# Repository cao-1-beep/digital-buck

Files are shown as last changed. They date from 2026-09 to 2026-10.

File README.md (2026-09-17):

# digital-buck

> 个人硬件项目：数字buck电源

## 项目内容

- `digital_buck/buck-firmware/Core/Inc/adc.h`
- `digital_buck/buck-firmware/Core/Inc/key.h`
- `digital_buck/buck-firmware/Core/Inc/main.h`
- `digital_buck/buck-firmware/Core/Inc/pid.h`
- `digital_buck/buck-firmware/Core/Inc/protect.h`
- `digital_buck/buck-firmware/Core/Inc/pwm.h`
- `digital_buck/buck-firmware/Core/Inc/stm32f1xx_hal_conf.h`
- `digital_buck/buck-firmware/Core/Inc/stm32f1xx_it.h`
- `digital_buck/buck-firmware/Core/Inc/storage.h`
- `digital_buck/buck-firmware/Core/Inc/uart.h`
- `digital_buck/buck-firmware/Core/Src/adc.c`
- `digital_buck/buck-firmware/Core/Src/key.c`
- `digital_buck/buck-firmware/Core/Src/main.c`
- `digital_buck/buck-firmware/Core/Src/pid.c`
- `digital_buck/buck-firmware/Core/Src/protect.c`
- `digital_buck/buck-firmware/Core/Src/pwm.c`
- `digital_buck/buck-firmware/Core/Src/stm32f1xx_it.c`
- `digital_buck/buck-firmware/Core/Src/storage.c`
- `digital_buck/buck-firmware/Core/Src/uart.c`
- `digital_buck/buck-firmware/readme.md`
- `digital_buck/keil_digital_buck.uvprojx`
- `drill.pdf`
- `keil_digital_buck.uvprojx`
- `PCB_Project/buck.PcbDoc`
- `PCB_Project/buck.SchDoc`
- `PCB_Project/digital_buck.OutJob`
- `PCB_Project/digital_buck.pdf`
- `PCB_Project/digital_buck.PrjPcb`
- `PCB_Project/digital_buck.PrjPcbStructure`
- `PCB_Project/digital_buck.xlsx`

## 使用工具

- **Altium Designer** —— 原理图 / PCB
- **Keil MDK + STM32** —— 固件源码

## 说明

- 本项目为个人学习与实践记录，供参考交流。
- 打样/复现前请自行复核原理图、器件参数与制板输出。
- 仓库内不含编译产物、仿真原始数据与第三方资料压缩包。

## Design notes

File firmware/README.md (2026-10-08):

# 数字降压电源 · 固件(DBC-2)

> 目标板:`hardware\digital-buck\PCB_Project\buck.SchDoc` / `buck.PcbDoc`(**板子已打样,硬件按原理图为准**)
> 主控:STM32F103C8T6 · 半桥同步整流(RT9624AZS + XR20N04 ×2)· L1 = 68μH
> 规格(2026-10-08 定):**输入 15 ~ 25V,输出 5 ~ 10V,≤ 2A**

---

## 一、你要做的 4 步

1. Keil 打开 **`MDK-ARM\DigitalBuck.uvprojx`**
2. `Build`(F7)
3. **第一次先选调试器**:`Options for Target`(Alt+F7)→ **Debug** 页 → 右上 `Use:` 选 **ST-Link Debugger**
   (工程从你的 `MOTOR.uvprojx` 派生,但我**没有给 `.uvoptx`** —— 调试器的选择存在那里,我不猜你 Keil 里 ST-Link 那条的驱动名。选一次以后 Keil 自己记住。)
4. `Download`(F8)

> **台架务必用限流电源。** 板上和电源端都没有保险丝,而**这颗板没有硬件过流比较器**(两颗运放 U2/U3 都用掉了),过流全靠软件,响应约几十μs。

---

## 二、你改过的 5 个元件(固件系数就是按它们推的)

| 元件 | 原值 | **现值** | 为什么改 | 对固件的影响 |
|:--|:--|:--|:--|:--|
| **R11** | 10mR | **30mR** | 提高信噪比;同时把运放失调折算的电流误差从 ±700mA 降到 ±233mA | 电流灵敏度 |
| **R19** | 100K | **30K** | 增益 50 → 15.7,采样链带宽 **20kHz → 64kHz** | **0.4706 V/A** |
| **C11** | 100nF | **1nF** | 采样极点 1.6kHz → 106kHz,不再是瓶颈 | 环路带宽 |
| **R20** | 10K | **3.3K** | 输出电压量程 6.6V → **13.3V** | Vout 分压 **0.2481** |
| **R30** | 1K | **68Ω** | NTC 饱和点从 ≈58°C 抬到 ≈150°C | NTC 换算 |

**? 如果以后有人把这些改回去,`adc.h` 里的系数必须同步改,否则读数全错。**

---

## 三、引脚表(原理图 + PCB 网表双证)

| MCU | 网络 | 用途 |
|:--|:--|:--|
| **PA10** | `PWM` | **单路 PWM → U4.RT9624 脚2**(TIM1_CH3) |
| **PA6** | `CUR_ADC` | 输出电流(U2 = LMV321 放大 15.7 倍,偏置 0.3765V) |
| **PA5** | `VIN_ADC` | 输入电压(U5B 缓冲,R21=10k/R23=1k ? 1:11) |
| **PA7** | `VFB_ADC` | 输出电压(U3 缓冲,R6=10K/R20=3.3K ? 0.2481) |
| **PA4** | `TEP_ADC` | 外部 NTC(MF52A103F3950,经 U5A 缓冲) |
| **PA1/PA2/PA3/PA0** | `PA1/PA2/PA3/PA0` | S1 电压+ / S2 电压? / S3 开关机 / S5 保存 |
| **PB6 / PB7** | `SCL` / `SDA` | I2C OLED(P4 排针) |
| **PA13 / PA14** | `SWDIO` / `SWCLK` | P3 排针 = 下载口 |
| NRST | `NRST` | 复位电路 + **S4 复位键** |

**板上没有**:LED(PC13 未连)、串口(PA9 悬空、PA10 已被 PWM 占用)、PB3/PB4/PB13~PB15。
电源链:`VIN` → U8(MG78M12N3)→ `+12` → U6(SPX1117-5.0)→ `+5` → U7(SPX1117-3.3)→ `+3.3V`

> **?? 单路 PWM,不是互补。** RT9624AZS 是单 PWM 输入、内部自产 UGATE/LGATE 和死区的半桥驱动 ?
> **死区由硬件给,固件不设 DTG**。原代码里的 `TIM1_CH1(PA8) + CH1N(PB13) 互补 + 100ns 死区`
> 在原理图和 PCB 上都没有对应引脚。

---

## 四、模拟前端系数(全部从原理图的电阻网推出来)

| 量 | 公式 | 量程 |
|:--|:--|:--|
| **输出电流** | `I[A] = (V_adc ? 0.3765) / 0.4706` | **?0.80 ~ +6.21A**(零电流 ≈ ADC 467) |
| **输入电压** | `Vin = V_adc × 11` | 36.3V |
| **输出电压** | `Vout = V_adc / 0.2481` | 13.3V |
| **温度** | `ratio = V_ntc / Vin`,`R_NTC = 68 × (1/ratio ? 1)`,`T[K] = 1/(1/298.15 + ln(R_NTC/10000)/3950)` | 0 ~ 150°C(≈22 码/°C) |

**三点说明:**
- **电流偏置 0.3765V 是算出来的,不是猜的**:1.2V 基准经 `R3(100K)/R5(1k)` 往 IN+ 注 23.5mV,再被增益放大 → 增益 51 时正好是 1.2V,你把增益改成 16 之后就变成 **0.3765V**。这也让**负向量程从 ?2.4A 缩到 ?0.80A**(你采的是单向负载电流,够用)。
- **上电会做电流零点标定**(输出关断时采 8 轮取平均),所以 LMV321 的输入失调(±7mV ? ±233mA)被吃掉。
- **NTC 是比例式**(以 VIN 为参考),`Vin` 自动消掉 —— 但 0°C 以下分辨率很差,所以**只用它做过温,不做低温判断**。

---

## 五、控制架构(这是相对原代码改动最大的地方)

```
电压外环 PID(5kHz) ──Icmd──> 电流内环 PID(50kHz) ──Duty──> TIM1_CH3(PA10) ──> RT9624 ──> 半桥
        ↑ Vout(PA7)                    ↑ Iout(PA6)                                     ↓
        └──────────── ADC1 四通道,TIM1 TRGO 触发 + DMA 环形 ?──────────────────────── L1/Vout
```

| 层 | 频率 | 干什么 | 为什么 |
|:--|:--|:--|:--|
| PWM 更新中断 | **100kHz** | 读电流(2 次浮点运算)+ **逐周期限流整数比较** + 分频计数 | 限流要快 |
| 电流内环 | **50kHz** | PID → 占空比 | 采样链带宽 64kHz(运放 GBW/增益),50kHz 采样终于是有意义的 |
| 电压外环 | **5kHz** | PID → 电流指令 | 电压环本来就慢 |
| 主循环 | — | Vin/Vout/NTC 换算、按键、OLED、Flash | 慢变量,不在中断里做 |

**为什么必须分频**:原代码在 10μs(720 周期)的预算里做 ADC 的浮点平均(12 次 int→float + 12 次加)+ 保护 + PID,按实际调用链估算 **15~29μs,超预算 1.5~3 倍**。分频后中断里最坏约 **12~15 次浮点运算 ≈ 300~400 周期**,余量约 2 倍。

> **上板后请用一个空闲 GPIO 在中断进出处翻转,示波器量实际宽度。** 估算不等于实测。

---

## 六、保护(全部软件)

| 层 | 阈值 | 动作 | 响应 |
|:--|:--|:--|:--|
| ① 逐周期限流 | **2.0A**(可改,0.1~2.0) | 本周期占空比压 0,下周期自动恢复 | **10μs** |
| ② 硬跳闸 | **3.2A**,连续 3 个周期 | 锁存 + 关输出,OLED 报 `OCP` | 30μs |
| ③ 输入欠压 | < 13.0V(消抖 50ms) | 关输出;回到 13.5V 自动清位(输出不自动开) | ms |
| ④ 输入过压 | > 26.5V(消抖 20ms) | 同上 | ms |
| ⑤ 输出过压 | > VSET×1.10 或 > 11.0V(3ms) | 锁存 | ms |
| ⑥ 过温 | **> 85°C**(100ms) | 锁存;回落到 75°C 以下才允许清除 | 100ms |
| ⑦ 过温降额 | **70°C 起** | 限流点从 2.0A 线性收到 1.0A | 100ms |

**?? 为什么跳闸是 3.2A 而不是更高**:电感 `L1 = xr1050-680m` 的**饱和电流只有 3.8A**,而最坏工况(25V→10V/2A)的纹波是 0.88A p-p ? 半纹波 0.44A。`3.2 + 0.44 = 3.64A < 3.8A`,**故障时电感也不会饱和**。跳闸点若设到 3.6A,峰值会到 4.04A,**超过饱和点** —— 电感一旦饱和,后面电流就失控了。

**本板没有硬件过流比较器**,所以过流全靠上面 ① ② 两层。台架必须用限流电源。

---

## 七、界面与按键

**OLED(PB6=SCL / PB7=SDA,I2C)** 4 行状态页:

```
SET 5.00V   CV|CC|故障名      第1行:设定值 + 模式(有故障时显示 OCP/OTP/OVIN/UVIN)
OUT 5.02V                     第2行:实际输出电压
IO  1.25A   LMT               第3行:输出电流(限流触发时亮 LMT,保持 1 秒)
IN 15.2V    42C               第4行:输入电压 + 温度
```

**按键**(按下为低;板上已有 10K 上拉 + 100nF,固件再开内部上拉做双保险):

| 键 | 引脚 | 短按 | 长按(800ms) | 长按后连按 |
|:--|:--|:--|:--|:--|
| S1 | PA1 | 电压 +0.1V | +0.5V | +0.1V/150ms |
| S2 | PA2 | 电压 ?0.1V | ?0.5V | ?0.1V/150ms |
| S3 | PA3 | 开关机 | **清故障** | — |
| S5 | PA0 | **保存参数**(停机时才允许) | **恢复出厂默认** | — |

**S4 是复位键(接 NRST)**,固件里不存在。

**上电默认关闭输出**,必须按 S3 才输出。

---

## 八、台架调试顺序

> 前 3 步不要接负载。

1. **只上 3.3V**(可从 P3.1 供)。看 OLED 是否亮、显示 `SET 5.00V CV`。不亮 → 先查 PB6/PB7 与上拉。
2. **量 PA10 静止电平**:应为**低**(MOE=0 + OSSI=1 ? 主动拉低)。若悬空/高 ? 查 `PWM_Init` 的 OSSI 配置。
3. **按 S3 开机**,示波器看 PA10:应有 **100kHz 方波**,占空比随软启动从 0 升到约 42%。频率不对 → 查 Y1(应为 8MHz)。
4. **电流零点**:开机后 OLED 的 `IO` 应显示 ≈ 0.00A(上电已自动标定)。若明显非零 → 用 `ADC_GetZeroRaw()` 在 Keil Watch 里看,正常约 467。
5. **接限流电源(先限到 0.2A)、不接负载**,确认 Vin 读数与电源表一致(分压 1:11)。
6. **接电子负载**,从 0.2A 慢慢加,看 `IO` 读数与外部分流器是否一致。不一致就按实测改 `ADC_IOUT_V_PER_A`。
7. **PID 整定**:
   - **先内环**:`Control_SetIpid(0.05, 200, 0)` 起步,加负载看阶跃;振荡→减 Kp/Ki,太慢→加。
   - **再外环**:`Control_SetVpid(0.3, 50, 0)` 起步,同理。
   - 用 **Keil 的 Watch 窗口 + Logic Analyzer**(通过 SWD 周期性读变量)把 `duty`/`ADC_GetIout()`/`ADC_GetVout()` 画成曲线 —— **不需要额外硬件**。
8. **过温**:用热风枪或电烙铁靠近 NTC,看 OLED 温度上升、70°C 起 `IO` 上限被压低、85°C 报 `OTP` 停机。
9. **过流**:把负载设成恒流 2.5A,应看到 `LMT` 闪烁(限流在起作用),而不是跳闸;再把负载短路(经限流电源!),应在几十μs 内 `OCP` 停机。
10. **保存参数**:停机后按 S5,应显示 `SAVED`;断电重上,参数应恢复。

---

## 九、我保证不了什么(必看)

| 项 | 实情 |
|:--|:--|
| **从未编译过** | 我这边没有 armcc。静态自查做了(嵌套注释、括号平衡、调用/声明一致性、单一定义、文件引用)、人工复核抓出并修掉了 3 个 bug(见下),但**第一次 Build 可能还有小错**,把报错贴给我改 |
| **模拟系数是"从电阻值推算",不是实测** | 0.4706 V/A、0.3765V 偏置、1:11、0.2481 都是算出来的。**第 4/6 步必须实测核对**,不一致就改 `adc.h` 里的宏 |
| **中断耗时是估算** | 300~400 周期是算的。**请按第五节用 GPIO + 示波器实测** |
| **温度是"板温近似"** | NTC 测的是它所在位置附近的温度,不等于 MOSFET 结温。降额阈值按板温定 |
| **`R1/R2/C1/C10` 原理图里没填值** | 其中 R2/C1 是开关节点 RC 吸收,你说是吸收回路、先不管 ? **损耗与振铃的实测数据里会包含它,但我没法建模** |

**我在这轮抓到并修掉的 3 个 bug(记录一下,免得你以为是"一次就对"):**
1. `ADC_Init` 里零点标定会**死等** —— 因为 TIM1 的 **TRGO 没设 `MMS`**(默认只跟软件 `UG` 位走),ADC 永远不会被硬件触发。**后果是上电即卡死。**
2. **MOE=0 时 TIM1 输出高阻** —— 没设 `OSSI`,RT9624 的 PWM 输入会悬空,**半桥有误开/直通风险**。已设 `OSSI/OSSR`,MOE=0 时主动拉低。
3. **`Protect_SetOcp` 语义冲突** —— 你的原意是"跳闸阈值",我在保护层里写成了"限流阈值"。已拆成 `Protect_SetLimit`(限流)与 `Protect_SetOcp`(跳闸)。

---

## 十、相对你原来那份代码,改了什么

| 文件 | 改动 |
|:--|:--|
| `pwm.h/.c` | 互补 `CH1(PA8)+CH1N(PB13)+DTG 死区` → **单路 `CH3(PA10)`**;补 `MMS=TRGO_UPDATE` 与 `OSSI/OSSR`;计数器+中断改在 `PWM_Init` 里启动(ADC 的触发源) |
| `adc.h/.c` | 通道 `PA0/1/2` → **`PA6 电流 / PA5 Vin / PA7 Vout / PA4 NTC`**;系数按你的实际电路重推;加零点标定;浮点移出中断;`logf` 每 100 次才跑 |
| `pid.h/.c` | 100kHz 全量 → **100k 只采样限流 / 50k 电流环 / 5k 电压环**;`VSET` 改 5~10V;加 `Vout ≤ 0.85×Vin` 钳位;加过温降额入口 |
| `protect.h/.c` | 硬件比较器过流(PA3/PA4)→ **软件三段**(逐周期限流 / 连续跳闸 / 慢保护);加过温;两个阈值分开 |
| `key.h/.c` | `PB0~PB4` 五键 + 关 JTAG → **`PA0~PA3` 四键**;**不再关 JTAG**(顺带保住 SWO 的可能) |
| `storage.h/.c` | 默认值更新;加 `temp_max`(历史最高温);**加"只在停机时才允许落盘"的门**;版本 1→2 |
| `ui.h/.c` | **新增**:I2C OLED 状态页 |
| `main.h/.c` | 删 LED / 删串口命令台 / 删遥测;薄主循环 + 按键动作 |
| `stm32f1xx_it.c` | 只留 `SysTick` + `TIM1_UP`;删 USART1 与 DMA 中断 |
| `uart.h/.c` | **不参与编译**(板上没有串口)。文件原样保留,你要用随时加回工程 |
| `basp/OLED.h/.c` | 引脚 `PB8/PB9` → **`PB6/PB7`**;补 `__HAL_RCC_GPIOB_CLK_ENABLE()`;`OLED_Init` 里的 GPIO 初始化也跟着改(否则初始化和收发不是同一对脚) |

**没动的**:`digital_buck\`(你的原代码)、`PCB_Project\`、`MOTOR程序\` —— 一个字节都没改。

**代码里预留的调试口**:`uart.c` 不编译,但如果你以后想用 **SWO(ITM printf)**,只要把 PB3 从 MCU 飞线到 ST-Link 的 SWO 脚,再把 `uart.c` 的底层输出换成 ITM 就行(这份代码的排版和注释都是按可打印写的)。

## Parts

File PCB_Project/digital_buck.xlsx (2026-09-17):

Comment | Description | Designator | Footprint | LibRef | Quantity
？ | 无极性电容 | C1, C10 | C-RAD-0603 | Cap | 2
Cap Pol | 极性电解电容 | C2, C4, C5 | CAP-TH_BD6.0-P2.50-D0.5-FD | Cap Pol | 3 | 买
100nF | 无极性电容 | C3, C6, C9, C11, C15, C16, C18, C20, C21, C22, C27, C28, C29, C30, C31, C32, C33, C35, C36, C39, C41, C42, C43, C44 | C-RAD-0603 | Cap | 24
10uF | 无极性电容 | C7, C8, C23, C37, C38, C40 | C-RAD-0603 | Cap | 6
10nF | 无极性电容 | C12, C17, C26, C34 | C-RAD-0603 | Cap | 4
1uF | 无极性电容 | C13, C14, C19 | C-RAD-0603 | Cap | 3
16pF | 无极性电容 | C24, C25 | C-RAD-0603 | Cap | 2
ss54f_c18199179 | 二极管配置:独立式;正向压降(Vf):550mV@5.0A;直流反向耐压(Vr):40V;整流电流:5A; | D1 | SMAF_L3.5-W2.6-LS4.7-RD-1 | SS54F | 1 | 买
Diode | 二极管 | D2, D3 | SMA_L4.3-W2.6-LS5.0-FD | Diode | 2
xr1050-680m | 电感值:68uH;精度:±20%;额定电流:3A;饱和电流(Isat):3.8A; | L1 | IND-SMD_L11.5-W10.1_XR1050-680M | xr1050-680m | 1 | 买
WJ500V-5.08-2P | 接线端子 | P1, P2 | CONN-TH_2P-P5.00_WJ500V-5.08-2P | WJ500V-5.08-2P | 2
Header 4 | 接插件 | P3, P4 | HDR4X1_A | Header 4 | 2
Header 2 | 接插件 | P5 | HDR2X1_A | Header 2 | 1
xr20n04 | 数量:1个N沟道;漏源电压(Vdss):40V;连续漏极电流(Id):20A;导通电阻(RDS(on)):40mΩ@10V;耗散功率(Pd):4W;阈值电压(Vgs(th)):2.2V; | Q1, Q2 | TO-252-3L_L6.6-W6.1-P4.60-LS9.5-BR-CW | XR20N04 | 2 | 买
? | 贴片电阻 | R1, R2 | 0603-1 | Res1 | 2
100K | 贴片电阻 | R3, R19, R32, R33 | 0603-1 | Res1 | 4
1K | 贴片电阻 | R4, R5, R13, R17, R18, R23, R30 | 0603-1 | Res1 | 7
10K | 贴片电阻 | R6, R9, R10, R14, R20, R21, R24, R25, R26, R27, R28 | 0603-1 | Res1 | 11
10R | 贴片电阻 | R7, R8, R12, R15, R16, R22, R29 | 0603-1 | Res1 | 7
10mR | 贴片电阻 | R11 | 2512 | Res1 | 1
3.3k | 贴片电阻 | R31 | 0603-1 | Res1 | 1
SW-PB | 微动开关 | S1, S2, S3, S4, S5 | SW_PB2_A1 | SW-PB | 5
STM32F103C | STM32单片机48引脚 | U1 | LQFP-48_M | STM32F103C | 1
LMV321-L | 比较器 | U2, U3 | SOT-23-5_L3.0-W1.7-P0.95-LS2.8-BR | TLV3201AIDBVR | 2 | 换
rt9624azs | 驱动配置:半桥;负载类型:MOSFET;驱动通道数:2;灌电流(IOL):-;拉电流(IOH):-;工作电压:4.5V~13.2V;上升时间(tr):24ns；25ns;下降时间(tf):12ns; | U4 | SOP-8_L4.9-W3.9-P1.27-LS6.0-BL-1 | RT9624AZS | 1 | 买
HT358VRZ | 双运放 | U5 | NSO8_N | LM358 | 1
SPX1117M3-5.0 | 5.0V稳压芯片 | U6 | SOT-223 | SPX1117M3-5.0 | 1
SPX1117M3-3.3 | 3.3V稳压芯片 | U7 | SOT-223 | SPX1117M3-3.3 | 1
MG78M12N3 | 最大30V转12V，压差当电压大于3V时为1.8v，小于3V时为2.3V | U8 | SOT-89-3_L4.5-W2.5-P1.50-LS4.2-BR | MG78M12N3 | 1 | 买
LM385M3-1.2/TR |  | U9 | SOT-23-3_L2.9-W1.3-P1.90-LS2.4-BR | LM385M3-1.2/TR | 1
XTAL | 晶振 | Y1 | X-SM49 | XTAL | 1

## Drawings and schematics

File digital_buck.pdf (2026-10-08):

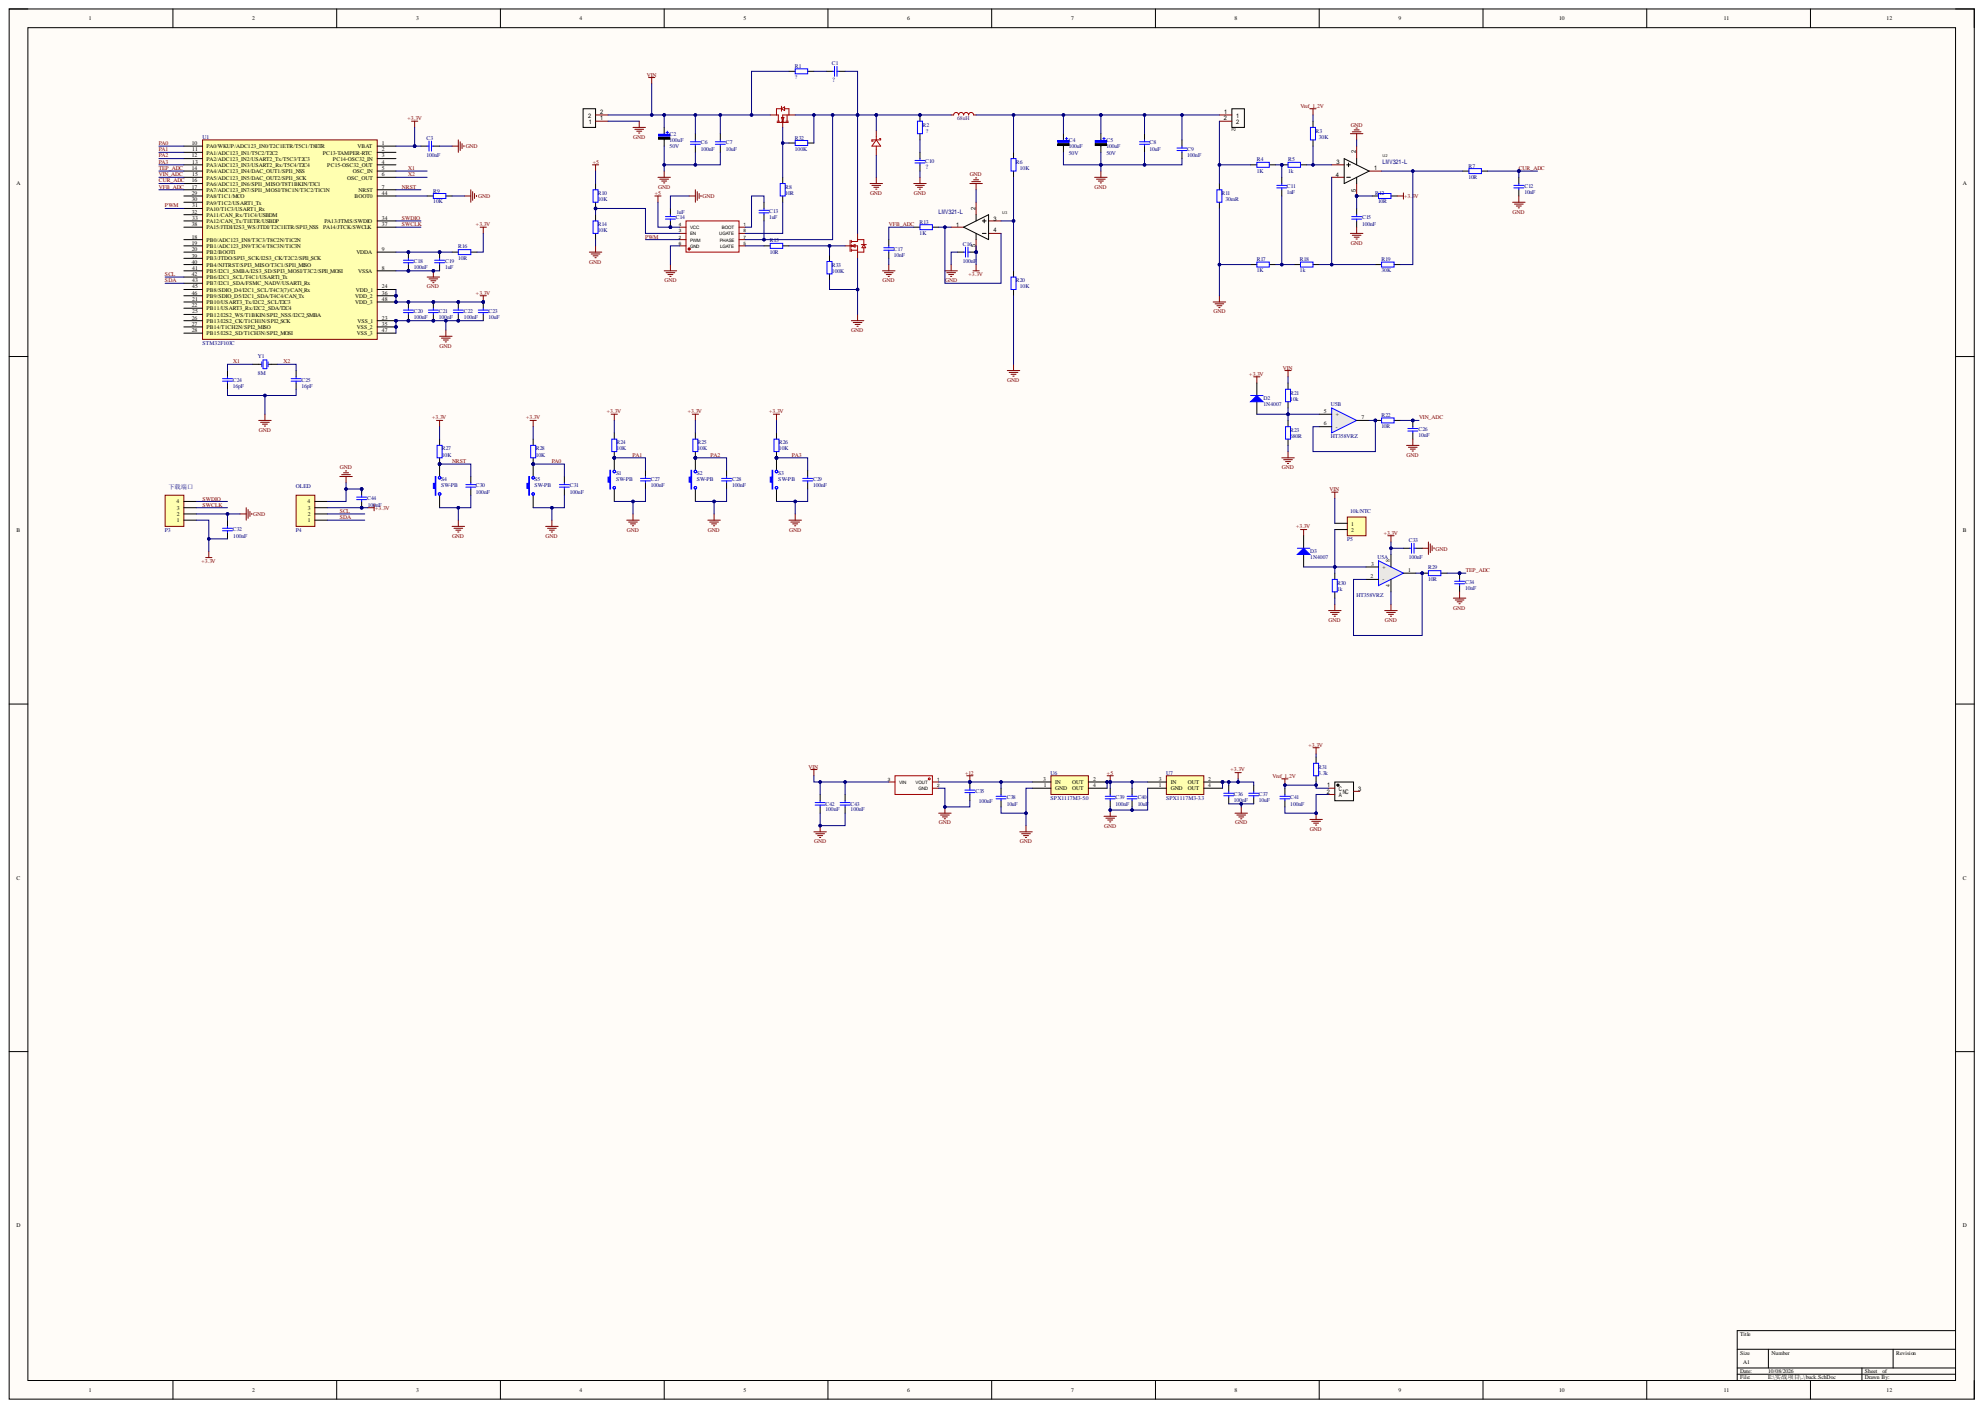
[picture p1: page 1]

Comment | Description | Designator | Footprint | LibRef | Quantity
？ | 无极性电容 | C1, C10 | C-RAD-0603 | Cap | 2
Cap Pol | 极性电解电容 | C2, C4, C5 | CAP-TH_BD6.0-P2.50-D0.5-FD | Cap Pol | 3
100nF | 无极性电容 | C3, C6, C9, C15, C16, C18, C20, C21, C22, C27, C28, C29, C30, C31, C32, C33, C35, C36, C39, C41, C42, C43, C44 | C-RAD-0603 | Cap | 23
10uF | 无极性电容 | C7, C8, C23, C37, C38, C40 | C-RAD-0603 | Cap | 6
1nF | 无极性电容 | C11 | C-RAD-0603 | Cap | 1
10nF | 无极性电容 | C12, C17, C26, C34 | C-RAD-0603 | Cap | 4
1uF | 无极性电容 | C13, C14, C19 | C-RAD-0603 | Cap | 3
16pF | 无极性电容 | C24, C25 | C-RAD-0603 | Cap | 2
ss54f_c18199179 | 二极管配置:独立式; 正向压降 (Vf):550mV@5.0A;直 流反向耐压(Vr):40V; 整流电流:5A; | D1 | SMAF_L3.5-W2.6-LS4.7-RD-1 | SS54F | 1
Diode | 二极管 | D2, D3 | SMA_L4.3-W2.6-LS5.0-FD | Diode | 2
xr1050-680m | 电感值:68uH;精度:± 20%;额定电流:3A;饱 和电流(Isat):3.8A; | L1 | IND-SMD_L11.5-W10.1_XR1050-680M | xr1050-680m | 1
WJ500V-5.08-2P | 接线端子 | P1, P2 | CONN-TH_2P-P5.00_WJ500V-5.08-2P | WJ500V-5.08-2P | 2
Header 4 | 接插件 | P3, P4 | HDR4X1_A | Header 4 | 2
Header 2 | 接插件 | P5 | HDR2X1_A | Header 2 | 1
xr20n04 | 数量:1个N沟道;漏源 电压(Vdss):40V;连续 漏极电流(Id):20A;导 通电阻(RDS(on)):40m Ω@10V;耗散功率 (Pd):4W;阈值电压 (Vgs(th)):2.2V; | Q1, Q2 | TO-252-3L_L6.6-W6.1-P4.60-LS9.5-BR-CW | XR20N04 | 2
? | 贴片电阻 | R1, R2 | 0603-1 | Res1 | 2
30K | 贴片电阻 | R3, R19 | 0603-1 | Res1 | 2
1K | 贴片电阻 | R4, R5, R13, R17, R18, R30 | 0603-1 | Res1 | 6
10K | 贴片电阻 | R6, R9, R10, R14, R20, R21, R24, R25, R26, R27, R28 | 0603-1 | Res1 | 11
10R | 贴片电阻 | R7, R8, R12, R15, R16, R22, R29 | 0603-1 | Res1 | 7
30mR | 贴片电阻 | R11 | 2512 | Res1 | 1
680R | 贴片电阻 | R23 | 0603-1 | Res1 | 1
3.3k | 贴片电阻 | R31 | 0603-1 | Res1 | 1
100K | 贴片电阻 | R32, R33 | 0603-1 | Res1 | 2
SW-PB | 微动开关 | S1, S2, S3, S4, S5 | SW_PB2_A1 | SW-PB | 5
STM32F103C | STM32单片机48引脚 | U1 | LQFP-48_M | STM32F103C | 1
LMV321-L | 比较器 | U2, U3 | SOT-23-5_L3.0-W1.7-P0.95-LS2.8-BR | TLV3201AIDBVR | 2
RT9624AZS | 驱动配置:半桥;负载 类型:MOSFET;驱动通 道数:2;灌电流(IOL):-; 拉电流(IOH):-;工作 电压:4.5V~13.2V;上 升时间(tr):24ns； 25ns;下降时间 (tf):12ns; | U4 | SOP-8_L4.9-W3.9-P1.27-LS6.0-BL-1 | RT9624AZS | 1
HT358VRZ | 双运放 | U5 | NSO8_N | LM358 | 1
SPX1117M3-5.0 | 5.0V稳压芯片 | U6 | SOT-223 | SPX1117M3-5.0 | 1
SPX1117M3-3.3 | 3.3V稳压芯片 | U7 | SOT-223 | SPX1117M3-3.3 | 1
MG78M12N3 | 最大30V转12V，压 差当电压大于3V时为 1.8v，小于3V时为 2.3V | U8 | SOT-89-3_L4.5-W2.5-P1.50-LS4.2-BR | MG78M12N3 | 1
LM385M3-1.2/TR | | U9 | SOT-23-3_L2.9-W1.3-P1.90-LS2.4-BR | LM385M3-1.2/TR | 1
XTAL | 晶振 | Y1 | X-SM49 | XTAL | 1

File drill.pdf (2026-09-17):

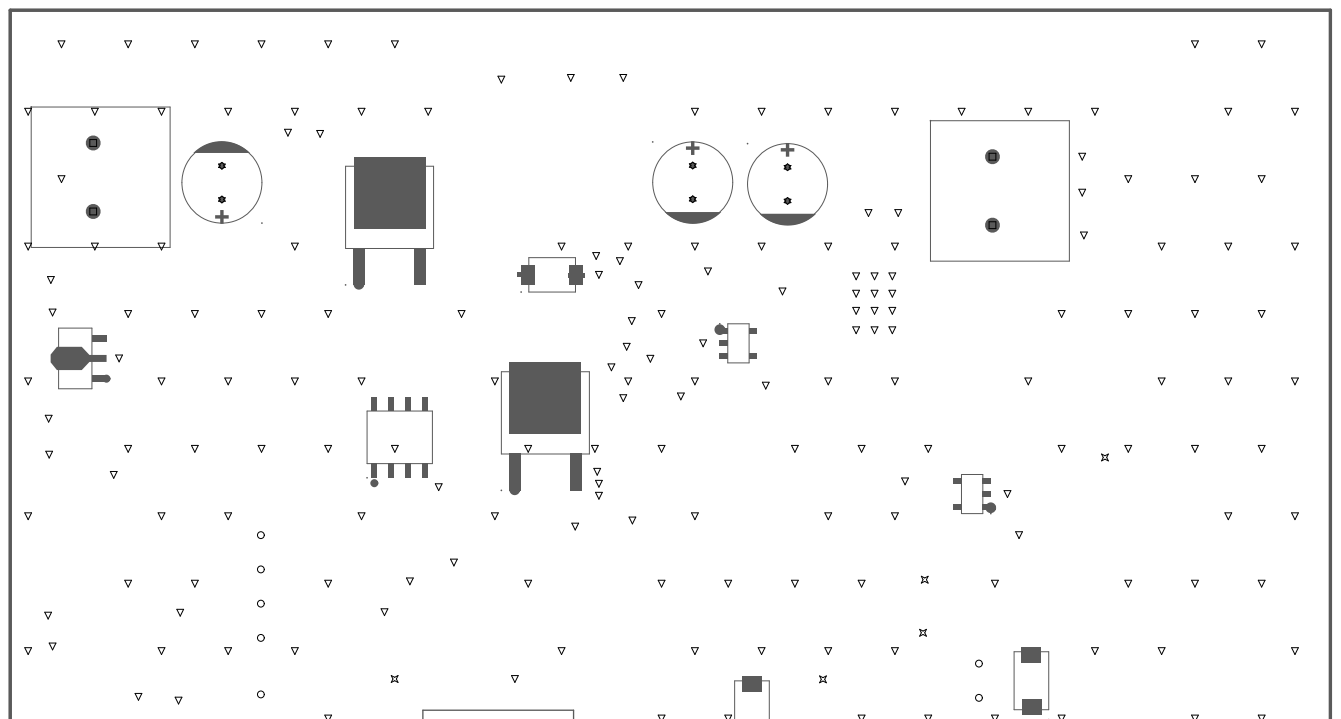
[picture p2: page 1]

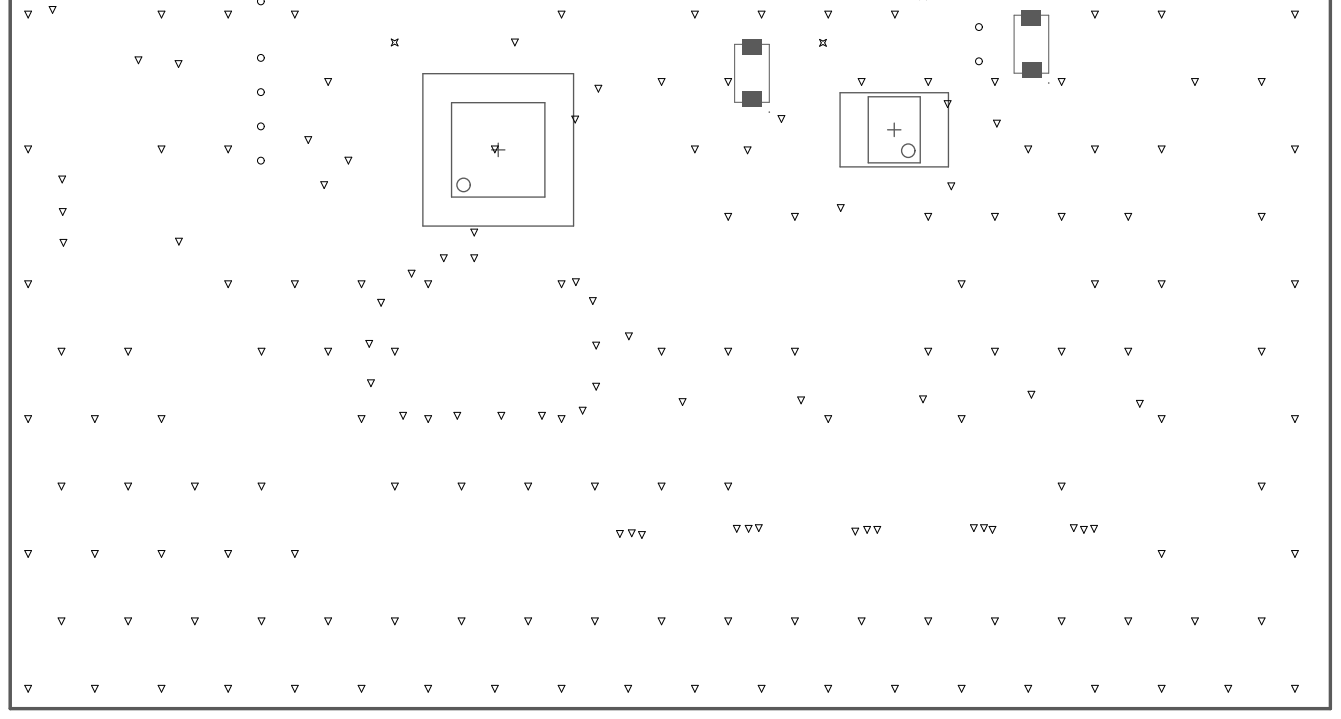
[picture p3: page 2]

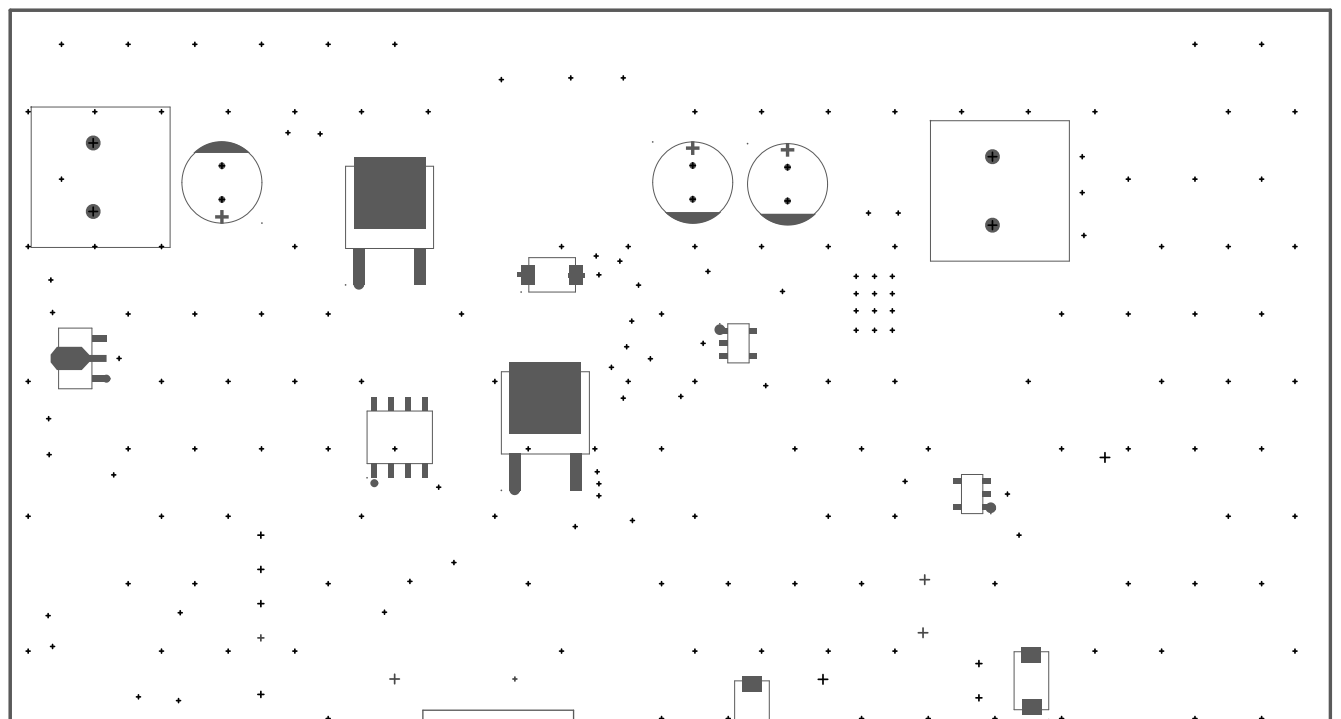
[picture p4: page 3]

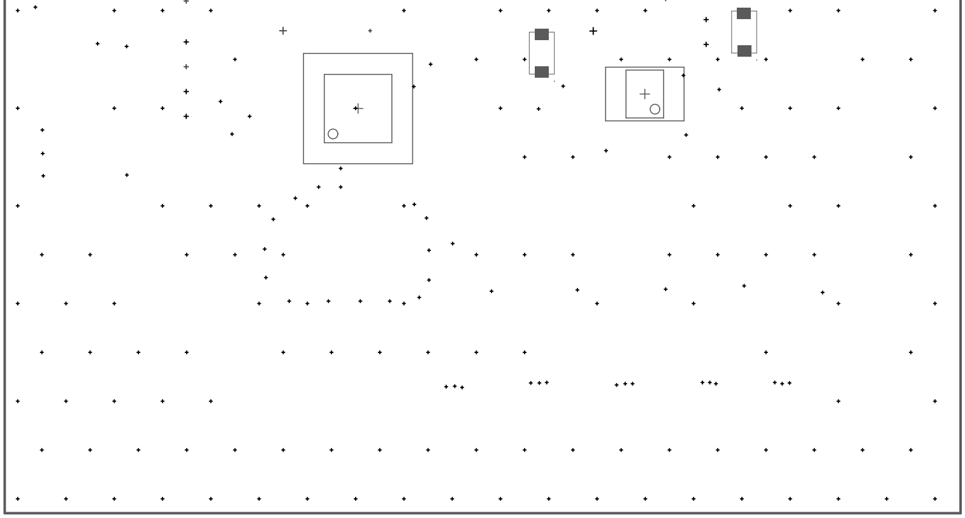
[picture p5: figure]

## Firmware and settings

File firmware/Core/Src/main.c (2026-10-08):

/**
 ******************************************************************************
 * @file    main.c
 * @brief   数字降压电源主程序
 *
 * 系统结构:
 *   电压外环 PID(5kHz) -> Icmd -> 电流内环 PID(50kHz) -> Duty
 *     -> TIM1_CH3(PA10) -> RT9624 -> 半桥(Q1/Q2) -> L1(68uH) -> Vout
 *   反馈:ADC1 四通道(TIM1 TRGO 触发 + DMA 环形)
 *     PA6 = 输出电流(U2 = LMV321,增益 15.7,偏置 0.3765V,R11 = 30mR)
 *     PA5 = 输入电压(1:11)   PA7 = 输出电压(1:2,R20 已改 3.3K)
 *     PA4 = 外部 NTC(MF52A103F3950,R30 = 68R)
 *
 * 主循环任务:
 *   KEY_Scan()          按键(内部 5ms 节流)
 *   Task1ms()           1ms:Vin/Vout/NTC 换算 -> 降额与钳位 -> 慢保护
 *   UI_Update()         OLED 状态页(内部 200ms 节流)
 *
 * [!] 本工程【不是 CubeMX 生成的】,没有 USER CODE 块。
 * [!] 本板没有串口(PA9 悬空、PA10 被 PWM 占用) => uart.c 不参与编译。
 * [!] 上电默认【关闭输出】;要输出必须按 S3(开关机)。
 ******************************************************************************
 */
#include "main.h"
#include "ui.h"

static void Task1ms(void);

int main(void)
{
  uint32_t last_1ms = 0U;
  uint32_t now;

  HAL_Init();

  /* 时钟:HSE 8MHz(原理图 Y1 的 Value = 8M)x PLL9 = 72MHz */
  SystemClock_Config();

  /* ---- 初始化顺序很重要,别调换 ----
   * 1) PWM_Init:TIM1 计数器 + 100kHz 中断先跑起来,它是 ADC 的触发源(TRGO)。
   *             MOE 仍然关着 => 栅极没有输出,安全。
   * 2) ADC_Init:启动 DMA + 做电流零点标定。
   *             此刻输出必然关断 => 标定到的就是真正的零点。 */
  PWM_Init();
  ADC_Init();

  PID_ControlInit();
  Protect_Init();
  Storage_LoadAndApply();     /* 从 Flash 读参数并应用(无效则用出厂默认) */
  KEY_Init();
  UI_Init();

  Control_Disable();          /* 再确认一次:上电默认关输出 */

  while (1)
  {
    KEY_Scan();

    now = HAL_GetTick();
    if (now != last_1ms)
    {
      last_1ms = now;
      Task1ms();
    }

    UI_Update();
  }
}

/*==================== 1ms 软节拍 ====================*/
static void Task1ms(void)
{
  ADC_UpdateSlow();          /* Vin / Vout / NTC 换算与平滑(NTC 内部再降速) */
  Control_Tick1ms();         /* 过温降额、Vset 钳位、欠压/过压/过温检查 */
  Storage_NoteTemp(ADC_GetTempC());   /* 记录历史最高温 */
}

/*==================== 按键事件(强定义,覆盖 key.c 里的弱符号)====================
 * 映射(按原理图):PA1 = S1 电压+ / PA2 = S2 电压- / PA3 = S3 开关机 / PA0 = S5 保存
 * 注:S4 接的是 NRST,是复位键,固件里不存在。
 */
void Key_OnEvent(uint8_t key, uint8_t evt)
{
  float v;

  switch (key)
  {
    /* ---- 电压 + ---- */
    case KEY_ID_UP:
      v = Control_GetVset();
      v += (evt == KEY_EVT_LONG) ? 0.5f : 0.1f;   /* 短按/连按 0.1V,长按 0.5V */
      Control_SetVset(v);
      break;

    /* ---- 电压 - ---- */
    case KEY_ID_DOWN:
      v = Control_GetVset();
      v -= (evt == KEY_EVT_LONG) ? 0.5f : 0.1f;
      Control_SetVset(v);
      break;

    /* ---- 开关机(长按:清故障)---- */
    case KEY_ID_PWR:
      if (evt == KEY_EVT_LONG)
      {
        Protect_ClearFaults();
        UI_Flash("CLR");
      }
      else if (evt == KEY_EVT_SHORT)
      {
        if (Control_IsEnabled() != 0U)
        {
          Control_Disable();
          UI_Flash("OFF");
        }
        else
        {
          Control_Enable();          /* 内部会清故障 + 软启动 */
          UI_Flash("ON");
        }
      }
      break;

    /* ---- 保存(长按:恢复出厂默认)---- */
    case KEY_ID_OK:
      if (evt == KEY_EVT_LONG)
      {
        Params_t p;
        Storage_Defaults(&p);
        Control_SetVset(p.vset);
        Control_SetIlimit(p.ilimit);
        Protect_SetOcp(p.ocp);
        Control_SetMode(p.mode);
        Control_SetVpid(p.vkp, p.vki, p.vkd);
        Control_SetIpid(p.ikp, p.iki, p.ikd);
        UI_Flash("FACTORY");
      }
      else if (evt == KEY_EVT_SHORT)
      {
        uint8_t r = Storage_SaveCurrent();
        if (r == 0U)       UI_Flash("SAVED");
        else if (r == 2U)  UI_Flash("STOP 1ST");   /* 运行中不许写 Flash */
        else               UI_Flash("SAVE ERR");
      }
      break;

    default:
      break;
  }
}

/*==================== 系统时钟 ====================
 * HSE 8MHz(原理图 Y1 Value=8M)x PLL9 = 72MHz
 * APB1 = 36MHz,APB2 = 72MHz,TIM1 挂 APB2 => 100kHz 对应 ARR = 719
 * ADC 时钟 = PCLK2/6 = 12MHz
 */
void SystemClock_Config(void)
{
  RCC_OscInitTypeDef       osc = {0};
  RCC_ClkInitTypeDef       clk = {0};
  RCC_PeriphCLKInitTypeDef per = {0};

  osc.OscillatorType = RCC_OSCILLATORTYPE_HSE;
  osc.HSEState       = RCC_HSE_ON;
  osc.HSEPredivValue = RCC_HSE_PREDIV_DIV1;
  osc.HSIState       = RCC_HSI_ON;
  osc.PLL.PLLState   = RCC_PLL_ON;
  osc.PLL.PLLSource  = RCC_PLLSOURCE_HSE;
  osc.PLL.PLLMUL     = RCC_PLL_MUL9;

  if (HAL_RCC_OscConfig(&osc) != HAL_OK)
  {
    /* HSE 起振失败:退回 HSI/2 x 16 = 64MHz。
     * 此时主频是 64MHz,开关频率会变成约 89kHz(ARR 按实际 PCLK2 算),
     * 只作应急——真出现这种情况要先查 Y1 和 C24/C25。 */
    osc.OscillatorType      = RCC_OSCILLATORTYPE_HSI;
    osc.HSIState            = RCC_HSI_ON;
    osc.HSEState            = RCC_HSE_OFF;
    osc.PLL.PLLSource       = RCC_PLLSOURCE_HSI_DIV2;
    osc.PLL.PLLMUL          = RCC_PLL_MUL16;
    if (HAL_RCC_OscConfig(&osc) != HAL_OK)
    {
      Error_Handler();
    }
  }

  clk.ClockType      = RCC_CLOCKTYPE_HCLK | RCC_CLOCKTYPE_SYSCLK
                     | RCC_CLOCKTYPE_PCLK1 | RCC_CLOCKTYPE_PCLK2;
  clk.SYSCLKSource   = RCC_SYSCLKSOURCE_PLLCLK;
  clk.AHBCLKDivider  = RCC_SYSCLK_DIV1;
  clk.APB1CLKDivider = RCC_HCLK_DIV2;      /* 36MHz */
  clk.APB2CLKDivider = RCC_HCLK_DIV1;      /* 72MHz */
  if (HAL_RCC_ClockConfig(&clk, FLASH_LATENCY_2) != HAL_OK)
  {
    Error_Handler();
  }

  per.PeriphClockSelection = RCC_PERIPHCLK_ADC;
  per.AdcClockSelection    = RCC_ADCPCLK2_DIV6;    /* 12MHz */
  if (HAL_RCCEx_PeriphCLKConfig(&per) != HAL_OK)
  {
    Error_Handler();
  }
}

/*==================== 错误处理 ====================
 * [!] 本板【没有 LED、没有蜂鸣器】,所以这里只能是"关输出 + 死等"。
 *     调试时在 while(1) 处打断点,或看 OLED 停在哪一屏来判断卡在哪一步。
 */
void Error_Handler(void)
{
  __disable_irq();
  while (1)
  {
  }
}

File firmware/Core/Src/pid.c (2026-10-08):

/**
 ******************************************************************************
 * @file    pid.c
 * @brief   双闭环实现 + 100kHz 控制中断入口
 *
 * 中断里的工作量(这是本文件最该被审的地方):
 *   ADC_OnPwmTick()          : 1 次整数转浮点 + 1 次减法 + 1 次除法
 *   Control_OnSample() 每周期: 2 次整数比较 + 1 次取模
 *                      每 2 周期: 1 次 PID(约 8 次浮点运算)
 *                      每 20 周期: 再 1 次 PID
 *   => 最坏周期约 12~15 次浮点运算, 估算 300~400 个周期
 *      预算 720 个周期(10us @72MHz) => 余量约 2 倍。
 *   [!] 上板后请用一个空闲 GPIO 在中断进出处翻转,示波器量实际宽度,
 *       不要相信估算,也不要相信"约数 us 属于正常设计"这种说法。
 ******************************************************************************
 */
#include "main.h"
#include "pid.h"
#include "adc.h"
#include "pwm.h"
#include "protect.h"

/*==================== 控制状态 ====================*/
volatile float   g_vset         = 5.0f;
volatile float   g_ilimit       = OCP_LIMIT_DEFAULT;
volatile uint8_t g_mode         = MODE_CV;
volatile uint8_t g_output_enabled = 0U;
volatile float   g_vset_eff     = 5.0f;
volatile float   g_ilimit_eff   = OCP_LIMIT_DEFAULT;

static PID_t    s_vpid;
static PID_t    s_ipid;
static uint32_t s_tick         = 0U;
static uint16_t s_trip_cnt     = 0U;
static uint8_t  s_limit_hit    = 0U;
static uint32_t s_limit_events = 0U;
static float    s_icmd         = 0.0f;
static uint32_t s_ss_ticks     = 0U;
static uint32_t s_ss_total     = 1U;
static uint8_t  s_soft_start   = 0U;

/*==================== 通用 PID(增量式,沿用原版算法)====================*/
void PID_Init(PID_t *p, float kp, float ki, float kd, float ts,
              float out_min, float out_max)
{
  p->kp = kp; p->ki = ki; p->kd = kd; p->ts = ts;
  p->out_min = out_min; p->out_max = out_max;
  p->setpoint = 0.0f; p->e1 = 0.0f; p->e2 = 0.0f; p->out = 0.0f;
}

void PID_SetParams(PID_t *p, float kp, float ki, float kd)
{
  p->kp = kp; p->ki = ki; p->kd = kd;
}

void PID_Reset(PID_t *p)
{
  p->e1 = 0.0f; p->e2 = 0.0f; p->out = 0.0f;
}

float PID_GetOut(const PID_t *p)
{
  return p->out;
}

float PID_Update(PID_t *p, float fb)
{
  float e  = p->setpoint - fb;
  float du = p->kp * (e - p->e1)
           + p->ki * p->ts * e
           + (p->kd / p->ts) * (e - 2.0f * p->e1 + p->e2);
  float u  = p->out + du;

  if (u > p->out_max) u = p->out_max;      /* 输出限幅 = 抗积分饱和 */
  if (u < p->out_min) u = p->out_min;

  p->e2 = p->e1;
  p->e1 = e;
  p->out = u;
  return u;
}

/*==================== 双闭环初始化 ====================*/
void PID_ControlInit(void)
{
  /* 电流内环:反馈输出电流(A) -> 输出占空比;Ts = 20us */
  PID_Init(&s_ipid, IPID_KP_DEFAULT, IPID_KI_DEFAULT, IPID_KD_DEFAULT,
           1.0f / (float)(PWM_FREQ_HZ / PID_ILOOP_DIV),
           0.0f, PWM_MAX_DUTY);

  /* 电压外环:反馈输出电压(V) -> 输出电流指令(A);Ts = 200us */
  PID_Init(&s_vpid, VPID_KP_DEFAULT, VPID_KI_DEFAULT, VPID_KD_DEFAULT,
           (float)PID_VLOOP_DIV / (float)PWM_FREQ_HZ,
           0.0f, ILIMIT_MAX);

  s_vpid.setpoint = g_vset;
  g_vset_eff      = g_vset;
  g_ilimit_eff    = g_ilimit;
  s_icmd          = 0.0f;
  s_limit_events  = 0U;
  s_tick          = 0U;

  /* 软启动总拍数(按电流环节拍数算) */
  s_ss_total = (SOFT_START_MS * (PWM_FREQ_HZ / 1000UL)) / PID_ILOOP_DIV;
  if (s_ss_total == 0U) s_ss_total = 1U;
}

/*==================== 使能 / 禁止 ====================*/
void Control_Enable(void)
{
  Protect_ClearFaults();          /* 使能时自动清故障(和原版行为一致) */
  PID_Reset(&s_ipid);
  PID_Reset(&s_vpid);
  s_vpid.setpoint = g_vset_eff;
  s_ipid.setpoint = 0.0f;
  s_icmd          = 0.0f;
  s_soft_start    = 1U;
  s_ss_ticks      = 0U;
  s_limit_events  = 0U;
  s_trip_cnt      = 0U;
  g_output_enabled = 1U;
  PWM_Enable();
}

void Control_Disable(void)
{
  g_output_enabled = 0U;
  s_soft_start     = 0U;
  PID_Reset(&s_ipid);
  PID_Reset(&s_vpid);
  s_icmd = 0.0f;
  PWM_Disable();                  /* 只清 MOE;计数器和中断继续跑 */
}

uint8_t Control_IsEnabled(void)
{
  return g_output_enabled;
}

/*==================== 主循环 1ms ====================*/
void Control_Tick1ms(void)
{
  float vin  = ADC_GetVin();
  float vout = ADC_GetVout();
  float t    = ADC_GetTempC();
  float sc, lim;

  /* ① 过温降额 -> 有效限流点(浮点只在这里算) */
  sc = Protect_ThermalScale();
  if (sc < 0.0f) sc = 0.0f;
  if (sc > 1.0f) sc = 1.0f;
  g_ilimit_eff = g_ilimit * sc;
  if (g_ilimit_eff < ILIMIT_MIN) g_ilimit_eff = ILIMIT_MIN;

  /* ② 电压设定钳位:Vout <= 0.85 x Vin(自举充电时间) */
  lim = VOUT_HEADROOM * vin;
  if (lim < VSET_MIN) lim = VSET_MIN;
  g_vset_eff = (g_vset < lim) ? g_vset : lim;

  /* ③ 慢保护:输入欠压/过压、输出过压、过温 */
  Protect_CheckSlow(vin, vout, t, g_vset_eff);
}

/*==================== 100kHz 中断里调用 ====================*/
void Control_OnSample(uint16_t raw, float amps)
{
  float duty, dmax, ramp;

  s_tick++;

  /* ---- ① 逐周期限流:纯整数比较,最快的一层 ---- */
  s_limit_hit = (raw >= g_limit_raw) ? 1U : 0U;

  /* ---- ② 硬跳闸:连续 OCP_DEBOUNCE 个 PWM 周期超跳闸点 ---- */
  if (raw >= g_trip_raw)
  {
    if (s_trip_cnt < 0xFFFFU) s_trip_cnt++;
  }
  else
  {
    s_trip_cnt = 0U;
  }
  if (s_trip_cnt >= OCP_DEBOUNCE)
  {
    Protect_Trip(FAULT_OCP);       /* 内部会 Control_Disable */
  }

  if (g_output_enabled == 0U)
  {
    PWM_SetDuty(0.0f);
    return;
  }

  /* 本周期过流:占空比压 0,下周期自动恢复(这就是逐周期限流) */
  if (s_limit_hit != 0U)
  {
    s_limit_events++;
    PWM_SetDuty(0.0f);
    return;
  }

  /* ---- ③ 电流内环节拍:每 PID_ILOOP_DIV 个周期算一次 ---- */
  if ((s_tick % PID_ILOOP_DIV) != 0U) return;

  /* 软启动:限制占空比上限 */
  dmax = PWM_MAX_DUTY;
  if (s_soft_start != 0U)
  {
    if (s_ss_ticks < s_ss_total) s_ss_ticks++;
    ramp = (float)s_ss_ticks / (float)s_ss_total;
    if (ramp >= 1.0f)
    {
      ramp = 1.0f;
      s_soft_start = 0U;
    }
    dmax = ramp * PWM_MAX_DUTY;
  }

  /* ---- ④ 电压外环节拍:每 PID_VLOOP_DIV 个周期算一次 ---- */
  if ((s_tick % PID_VLOOP_DIV) == 0U)
  {
    s_vpid.setpoint = g_vset_eff;
    s_vpid.out_max  = g_ilimit_eff;
    (void)PID_Update(&s_vpid, ADC_GetVout());
  }

  /* ---- ⑤ 电流指令 + 电流内环 ---- */
  if (g_mode == MODE_CC)
  {
    s_icmd = g_ilimit_eff;
  }
  else
  {
    s_icmd = PID_GetOut(&s_vpid);
    if (s_icmd < 0.0f)         s_icmd = 0.0f;
    if (s_icmd > g_ilimit_eff) s_icmd = g_ilimit_eff;
  }

  s_ipid.setpoint = s_icmd;
  duty = PID_Update(&s_ipid, amps);
  if (duty > dmax) duty = dmax;
  if (duty < 0.0f) duty = 0.0f;
  PWM_SetDuty(duty);
}

/*==================== 100kHz 中断入口 ====================
 * TIM1 更新中断 -> stm32f1xx_it.c 的 TIM1_UP_IRQHandler
 *                -> HAL_TIM_IRQHandler -> 这里
 * [!] 全工程只能有这一处 HAL_TIM_PeriodElapsedCallback 定义。
 */
void HAL_TIM_PeriodElapsedCallback(TIM_HandleTypeDef *htim)
{
  if (htim->Instance != TIM1) return;

  ADC_OnPwmTick();                                   /* 更新电流 + 扫描计数 */
  Control_OnSample(ADC_GetIoutRaw(), ADC_GetIout()); /* 限流 + 分频 PID */
}

/*==================== 参数读写 ====================*/
void Control_SetVset(float v)
{
  if (v < VSET_MIN) v = VSET_MIN;
  if (v > VSET_MAX) v = VSET_MAX;
  g_vset = v;
}

float Control_GetVset(void) { return g_vset; }

void Control_SetIlimit(float a)
{
  if (a < ILIMIT_MIN) a = ILIMIT_MIN;
  if (a > ILIMIT_MAX) a = ILIMIT_MAX;
  g_ilimit = a;
  Protect_SetLimit(a);        /* 同步刷新逐周期限流的整数阈值 */
}
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

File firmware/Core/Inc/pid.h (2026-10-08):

/**
 ******************************************************************************
 * @file    pid.h
 * @brief   双闭环控制(电压外环 + 电流内环)+ 100kHz 控制中断的入口
 *
 * 节拍分工 —— 这是本工程控制部分最核心的设计:
 *   100kHz(每 10us):读电流 -> 逐周期限流(整数比较)-> 计数分频
 *    50kHz(每 2 次):电流内环 PID -> 占空比
 *     5kHz(每 20 次):电压外环 PID -> 电流指令
 *
 * 为什么必须这么分(不是偷懒,是算出来的):
 *   ① 电流采样链的带宽 = LMV321 的 GBW(1MHz) / 闭环增益(15.7) ≈ 64kHz。
 *      所以"100kHz 的电流环"买不到更快的响应,只是让 CPU 更累。
 *   ② 原版在 10us 的预算里做 ADC 的浮点平均(12 次整数转浮点 + 12 次浮点加)
 *      + 保护 + PID,实测估算 15~29us,超预算 1.5~3 倍(会漏 PWM 更新)。
 *   ③ 分成 50kHz 之后,电流环每 20us 算一次,工作量只有几百个周期,余量充足。
 *
 * [!] 与代码原版在电流采样上的差别:
 *   原版按"增益 50 / 10mR / 无偏置"换算,而实际板上(你改过之后)是
 *   R11 = 30mR、增益 15.7、偏置 0.3765V => 见 adc.h
 ******************************************************************************
 */
#ifndef __PID_H
#define __PID_H

#ifdef __cplusplus
extern "C" {
#endif

#include <stdint.h>

/*============================== 用户配置区 ==============================*/
/* 分频:电压环 = PID_VLOOP_DIV x 10us;电流环 = PID_ILOOP_DIV x 10us */
#define PID_ILOOP_DIV    2UL      /* 2 x 10us = 20us  => 50kHz 电流环 */
#define PID_VLOOP_DIV    20UL     /* 20 x 10us = 200us => 5kHz 电压环 */

/* 软启动:使能输出后,占空比上限从 0 线性升到 PWM_MAX_DUTY */
#define SOFT_START_MS    50UL

/* 输出电压设定范围(本工程规格:5~10V) */
#define VSET_MIN         5.0f
#define VSET_MAX         10.0f

/* 限流/恒流设定范围(电感额定 3A、饱和 3.8A;你定 2A) */
#define ILIMIT_MIN       0.1f
#define ILIMIT_MAX       2.0f

/* 输出电压相对输入的上限:Vout <= 0.85 x Vin
 * 不是为了防直通,而是 RT9624 的自举电容要靠关断期充电 */
#define VOUT_HEADROOM    0.85f

/* 工作模式 */
#define MODE_CV          0        /* 恒压:电压环给电流指令,内环限流 */
#define MODE_CC          1        /* 恒流:内环直接跟设定电流 */

/* PID 初始参数(台架起点,可用 SWO/OLED 在线改)
 * 电流环:输入 A,输出占空比;Ts = 20us
 * 电压环:输入 V,输出 A;      Ts = 200us */
#define IPID_KP_DEFAULT  0.20f
#define IPID_KI_DEFAULT  800.0f
#define IPID_KD_DEFAULT  0.0f
#define VPID_KP_DEFAULT  0.40f
#define VPID_KI_DEFAULT  150.0f
#define VPID_KD_DEFAULT  0.0f
/*=======================================================================*/

/* 增量式 PID 控制器 */
typedef struct
{
  float kp, ki, kd;        /* 比例 / 积分 / 微分系数(ki 单位 1/s) */
  float ts;                /* 控制周期 (s) */
  float out_min, out_max;  /* 输出限幅(兼作抗积分饱和) */
  float setpoint;          /* 设定值 */
  float e1, e2;            /* 前两次误差 */
  float out;               /* 当前输出 */
} PID_t;

/* 控制状态(其他模块只通过 getter/setter 访问;volatile 保证跨中断可见) */
extern volatile float   g_vset;            /* 电压设定 (V) */
extern volatile float   g_ilimit;          /* 限流设定 (A) */
extern volatile uint8_t g_mode;            /* MODE_CV / MODE_CC */
extern volatile uint8_t g_output_enabled;  /* 输出使能 */

/* 由主循环 1ms 更新、供 100kHz 中断直接读取的三个"预算好的值"
 * (中断里不许做浮点换算,只许读) */
extern volatile float   g_vset_eff;        /* 钳位后的电压设定 */
extern volatile float   g_ilimit_eff;      /* 过温降额后的限流点 */

/* ---- 通用 PID ---- */
void  PID_Init(PID_t *p, float kp, float ki, float kd, float ts,
               float out_min, float out_max);
void  PID_SetParams(PID_t *p, float kp, float ki, float kd);
void  PID_Reset(PID_t *p);
float PID_Update(PID_t *p, float fb);
float PID_GetOut(const PID_t *p);

/* ---- 双闭环 ---- */
void    PID_ControlInit(void);
void    Control_Enable(void);
void    Control_Disable(void);
uint8_t Control_IsEnabled(void);

/* 主循环 1ms:算降额/钳位、跑慢保护 */
void    Control_Tick1ms(void);

/* [!] 100kHz 中断里调用(由 HAL_TIM_PeriodElapsedCallback 转进来)。
 *     raw = 电流通道原始码值(整数限流用), amps = 换算好的电流 */
void    Control_OnSample(uint16_t raw, float amps);

/* ---- 参数读写 ---- */
void    Control_SetVset(float v);
float   Control_GetVset(void);
void    Control_SetIlimit(float a);
float   Control_GetIlimit(void);
void    Control_SetMode(uint8_t m);
uint8_t Control_GetMode(void);
void    Control_SetVpid(float kp, float ki, float kd);
void    Control_SetIpid(float kp, float ki, float kd);
void    Control_GetVpid(float *kp, float *ki, float *kd);
void    Control_GetIpid(float *kp, float *ki, float *kd);
float   Control_GetIcmd(void);
uint8_t Control_GetLimitHit(void);
uint32_t Control_GetLimitEvents(void);

#ifdef __cplusplus
}
#endif

#endif /* __PID_H */

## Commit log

2026-09-17 init: STM32 数字 buck 电源（固件 / PCB / 计算）
    [buck.PcbDoc, buck.SchDoc, digital_buck.PrjPcb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]
2026-10-08 feat: 数字控制固件(按原理图改造,自包含 HAL);移除过期原固件与旧原理图 PDF
    [buck.SchDoc]
2026-10-08 docs: 更新原理图 PDF(导出至仓库根目录)
